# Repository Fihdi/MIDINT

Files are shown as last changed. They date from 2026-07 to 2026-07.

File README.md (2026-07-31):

# 6hp MIDI Interface (work in progress)
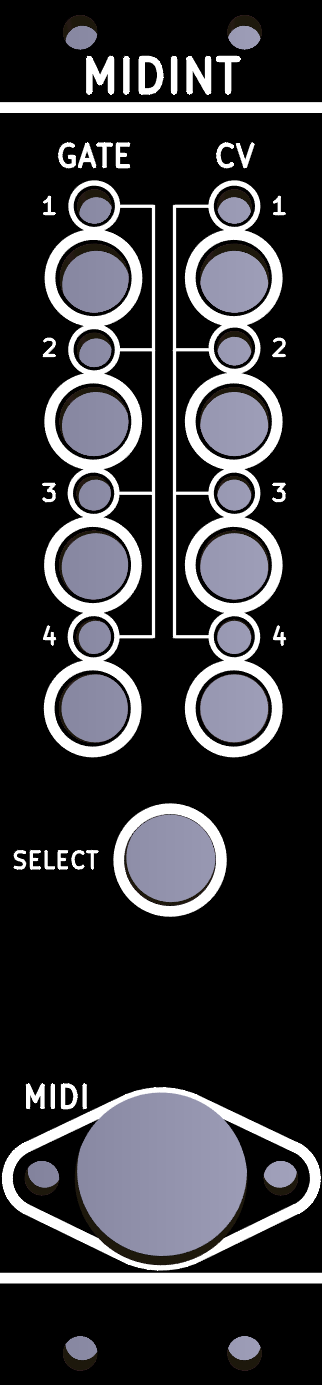
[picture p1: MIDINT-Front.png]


MIDINT is an eight channel MIDI interface in 6hp. Take a standard DIN-5 MIDI cable connected to your favorite DAW or MIDI gear and control up to eight Gate, Trigger and CV channels. Trimmers on the back of the module allow for precise V/Oct tuning. The CV outputs can thus control oscillators and filters without the need for an external quantizer.

Selecting a channel with the "SELECT" encoder and pressing it will switch it between a trigger or gate output.

# Features

- 4 Gate or Trigger outputs
- 4 CV outputs (Can also be used as Gate or Trigger outputs)
- Extension of up to three modules.

# Extension 

Its possible to daisy-chain up to three extension modules to one main module and expand your interface system to a maximum of 32 Gate/Trigger/CV channels. To connect extension module(s) to a main module:

WARNING: Do NOT connect main modules together!

- Turn your modular synthesizer off
- Take an extension module(s) and change the jumper from "MAIN" to "EXT".
- Add jumpers to "EXT1" and "EXT2" to configure the MIDI channels (see table below)
- Connect the extension module(s) to a main module or another extension module in the chain with a wire underneath the power connector.
- Connect each module(s) to power
- Turn your modular synthesizer on

By connecting a MIDI cable into the main module the MIDI data is shared between all modules. The extension modules are addressed by the jumper settings EXT1 and EXT2:

//TODO: Add address table

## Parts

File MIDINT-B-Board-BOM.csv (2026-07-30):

Reference | Qty | Value | DNP | Exclude from BOM | Exclude from Board | Footprint | Datasheet
A101 | 1 | Arduino_Nano_v3.x |  |  |  | Module:Arduino_Nano | http://www.mouser.com/pdfdocs/Gravitech_Arduino_Nano3_0.pdf
C101,C104,C105 | 3 | 100n |  |  |  | Capacitor_SMD:C_1206_3216Metric | ~
C103 | 1 | 10u |  |  |  | Capacitor_SMD:C_1206_3216Metric | ~
D4,D6,D8,D9,D10,D13,D14,D19,D20,D21,D22,D101 | 12 | D |  |  |  | Diode_SMD:D_SOD-323_HandSoldering | ~
J2,J3,J102,J103 | 4 | Conn_01x01_Pin |  |  |  | Connector_PinHeader_2.54mm:PinHeader_1x01_P2.54mm_Vertical | ~
J11 | 1 | Conn_02x05_Odd_Even |  |  |  | Connector_IDC:IDC-Header_2x05_P2.54mm_Vertical | ~
J19,J23 | 2 | Conn_01x04_Pin |  |  |  | Connector_PinHeader_2.54mm:PinHeader_1x04_P2.54mm_Vertical | ~
J104,J106 | 2 | Conn_01x02_Pin |  |  |  | Connector_PinHeader_2.54mm:PinHeader_1x02_P2.54mm_Vertical | ~
J105 | 1 | Conn_02x04_Odd_Even |  |  |  | Connector_PinHeader_2.54mm:PinHeader_2x04_P2.54mm_Vertical | ~
J107 | 1 | Conn_01x03_Pin |  |  |  | Connector_PinHeader_2.54mm:PinHeader_1x03_P2.54mm_Vertical | ~
R1,R2 | 2 | 220R |  |  |  | Resistor_SMD:R_1206_3216Metric | ~
R5,R7,R10,R12,R21,R23,R25,R27,R101,R103,R104 | 11 | 1k |  |  |  | Resistor_SMD:R_1206_3216Metric | ~
R6,R8,R11,R13 | 4 | 22k |  |  |  | Resistor_SMD:R_1206_3216Metric | ~
R19,R22,R24,R26 | 4 | 2k2 |  |  |  | Resistor_SMD:R_1206_3216Metric | ~
R108,R109 | 2 | 4k7 |  |  |  | Resistor_SMD:R_1206_3216Metric | ~
RV1,RV2,RV3,RV4 | 4 | 50k |  |  |  | Potentiometer_THT:Potentiometer_Bourns_3296W_Vertical | ~
U4 | 1 | L7805 |  |  |  | Package_TO_SOT_SMD:SOT-223 | http://www.st.com/content/ccc/resource/technical/document/datasheet/41/4f/b3/b0/12/d4/47/88/CD00000444.pdf/files/CD00000444.pdf/jcr:content/translations/en.CD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
U6 | 1 | TL074 |  |  |  | Package_SO:SOIC-14_3.9x8.7mm_P1.27mm | http://www.ti.com/lit/ds/symlink/tl071.pdf
U101 | 1 | 6N138 |  |  |  | Package_DIP:DIP-8_W7.62mm | http://www.onsemi.com/pub/Collateral/HCPL2731-D.pdf
U102 | 1 | DAC6573 |  |  |  | Package_SO:TSSOP-16_4.4x5mm_P0.65mm

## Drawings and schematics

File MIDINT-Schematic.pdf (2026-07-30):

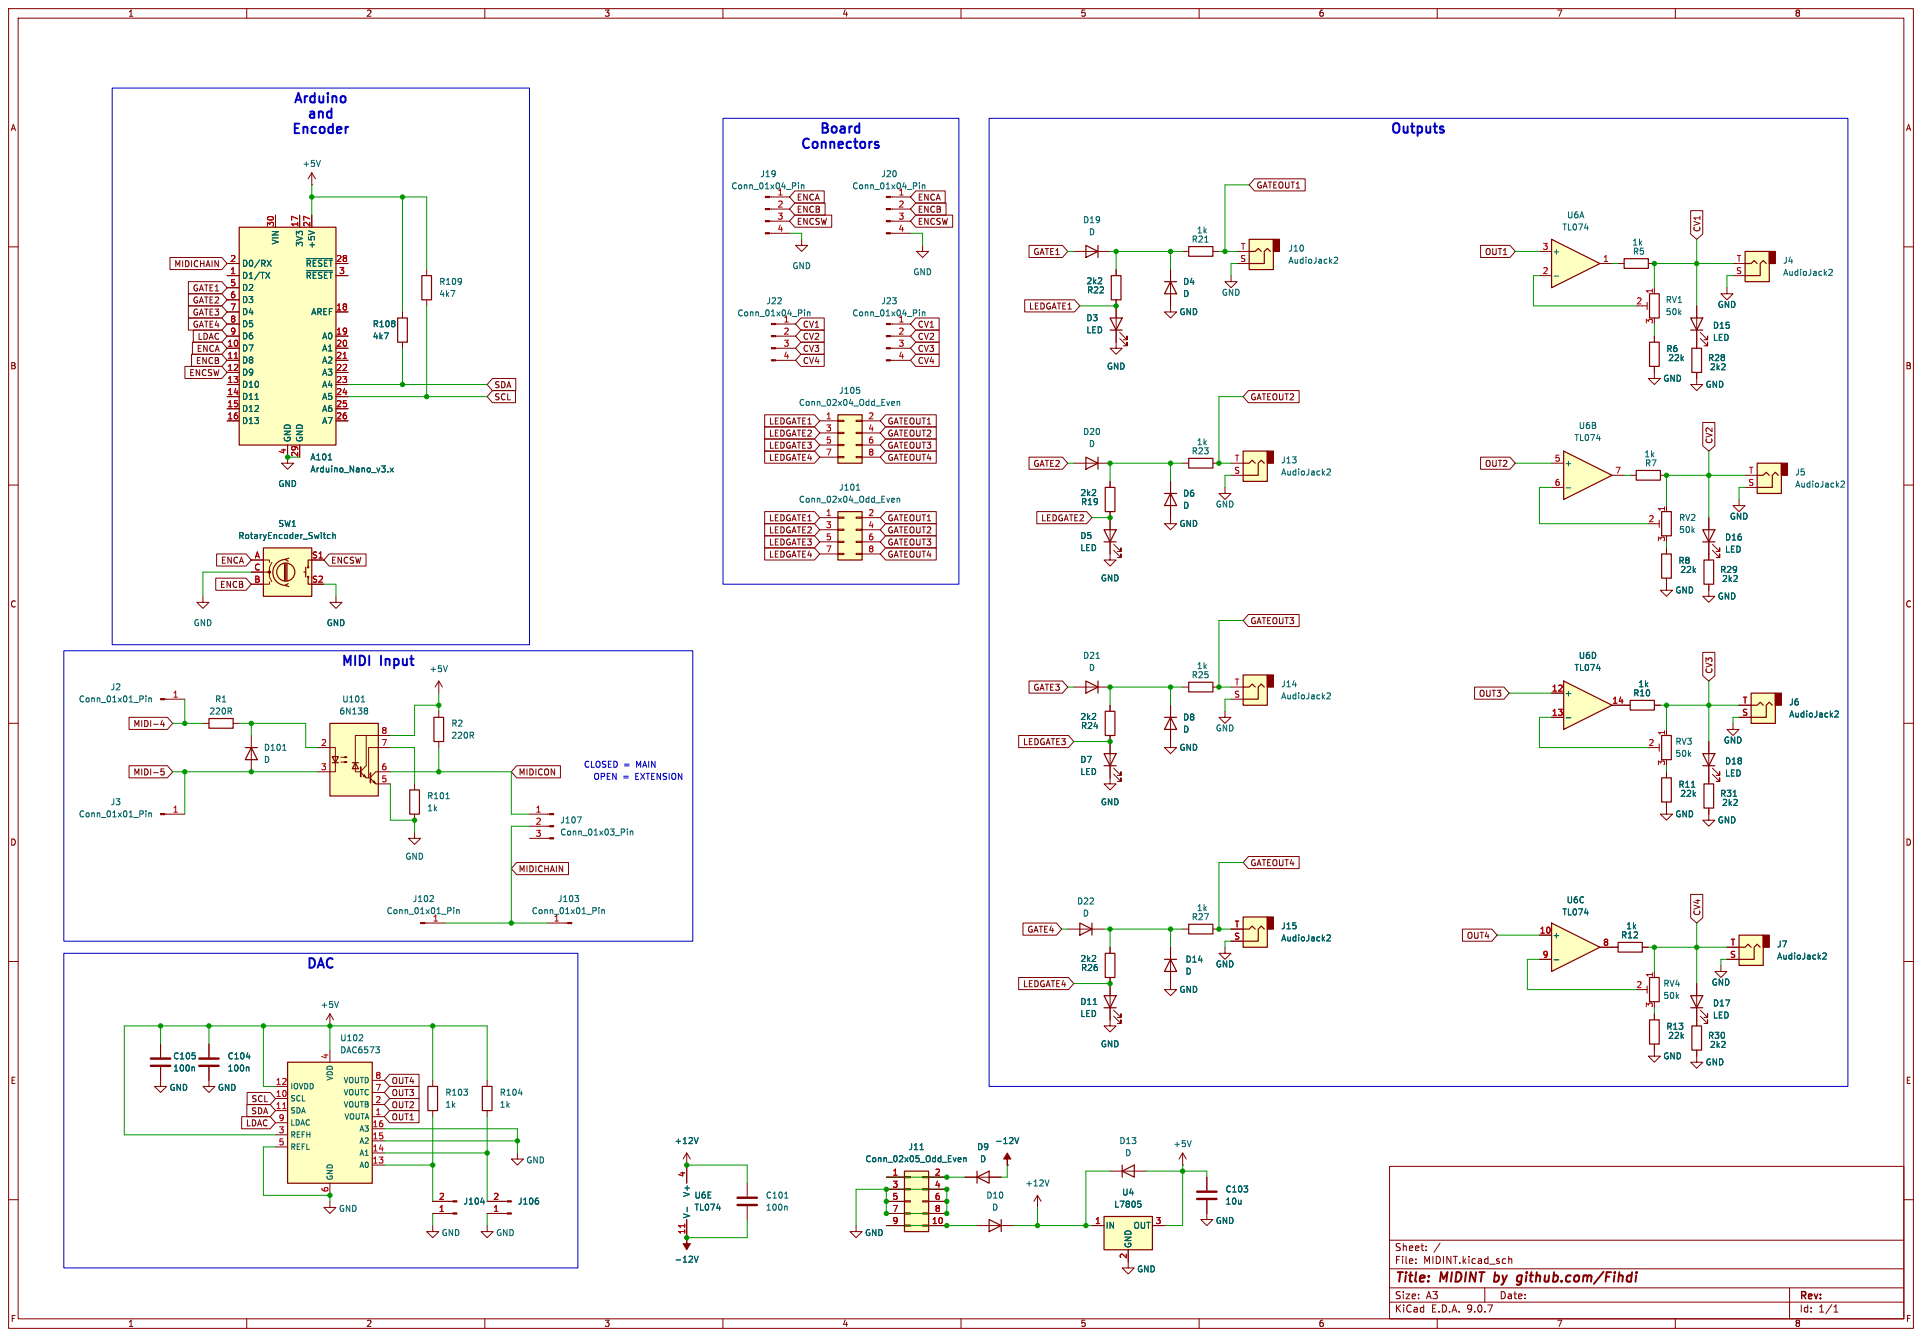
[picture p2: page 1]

CLOSED = MAIN OPEN = EXTENSION

6 VOUTD 8 VOUTC 7 VOUTB 2 VOUTA 1 A3 16 A2 15 A1 14 A0 13 U102 DAC6573 GND

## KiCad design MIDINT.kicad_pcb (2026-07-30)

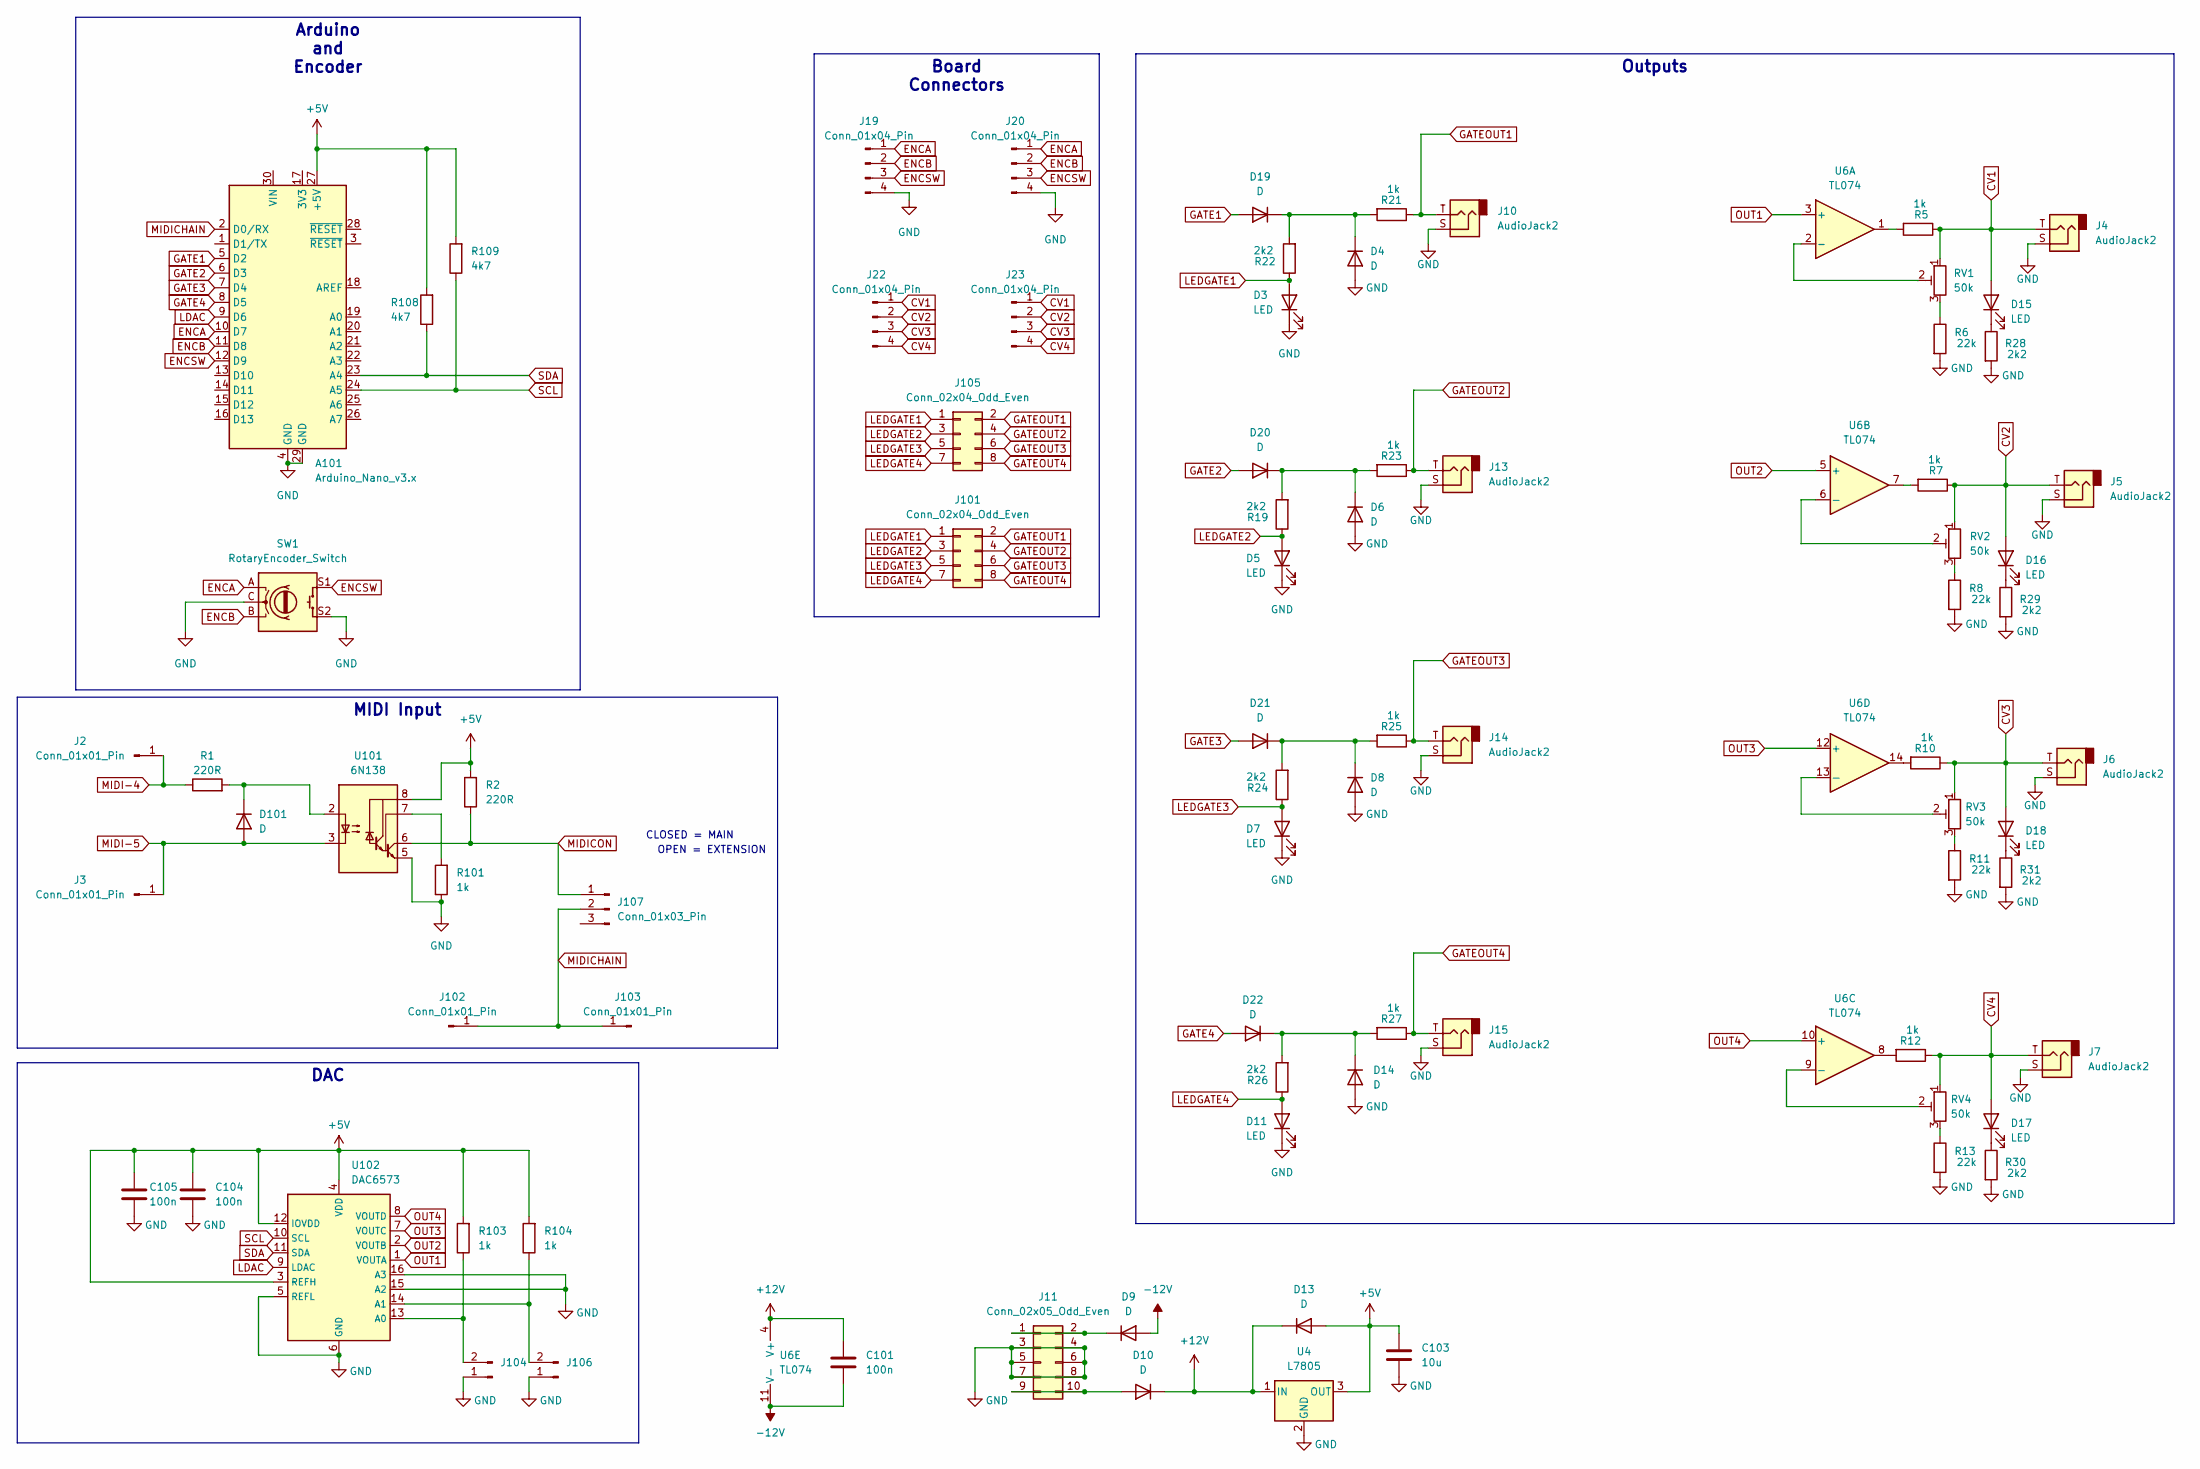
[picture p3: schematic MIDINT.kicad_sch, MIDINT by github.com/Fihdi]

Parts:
A101: Arduino_Nano_v3.x; Arduino_Nano
C101, C104, C105: 100n; C_1206_3216Metric
C103: 10u; C_1206_3216Metric
D3, D5, D7, D11, D15, D16, D17, D18: LED; LED_D3.0mm
D4, D6, D8, D9, D10, D13, D14, D19, D20, D21, D22, D101: D; D_SOD-323_HandSoldering
J2, J3, J102, J103: Conn_01x01_Pin; PinHeader_1x01_P2.54mm_Vertical
J4, J5, J6, J7, J10, J13, J14, J15: AudioJack2; MonoTRS
J11: Conn_02x05_Odd_Even; IDC-Header_2x05_P2.54mm_Vertical
J19, J20, J22, J23: Conn_01x04_Pin; PinHeader_1x04_P2.54mm_Vertical
J101, J105: Conn_02x04_Odd_Even; PinHeader_2x04_P2.54mm_Vertical
J104, J106: Conn_01x02_Pin; PinHeader_1x02_P2.54mm_Vertical
J107: Conn_01x03_Pin; PinHeader_1x03_P2.54mm_Vertical
R1, R2: 220R; R_1206_3216Metric
R5, R7, R10, R12, R21, R23, R25, R27, R101, R103, R104: 1k; R_1206_3216Metric
R6, R8, R11, R13: 22k; R_1206_3216Metric
R19, R22, R24, R26, R28, R29, R30, R31: 2k2; R_1206_3216Metric
R108, R109: 4k7; R_1206_3216Metric
RV1, RV2, RV3, RV4: 50k; Potentiometer_Bourns_3296W_Vertical
SW1: RotaryEncoder_Switch; RotaryEncoder_Alps_EC12E-Switch_Vertical_H20mm
U4: L7805; SOT-223
U6: TL074; SOIC-14_3.9x8.7mm_P1.27mm
U101: 6N138; DIP-8_W7.62mm
U102: DAC6573; TSSOP-16_4.4x5mm_P0.65mm

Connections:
+5V: A101.27 (+5V), C103.1, C104.1, C105.1, D13.2 (A), R2.2, R103.2, R104.2, R108.2, R109.2, U4.3 (OUT), U101.8 (VCC), U102.3 (REFH), U102.4 (VDD), U102.12 (IOVDD)
+12V: C101.1, D10.1 (K), D13.1 (K), U4.1 (IN), U6.4 (V+)
-12V: C101.2, D9.2 (A), U6.11 (V-)
CV1: D15.2 (A), J4.T, J22.1, J23.1, R5.1, RV1.1
CV2: D16.2 (A), J5.T, J22.2, J23.2, R7.1, RV2.1
CV3: D18.2 (A), J6.T, J22.3, J23.3, R10.1, RV3.1
CV4: D17.2 (A), J7.T, J22.4, J23.4, R12.1, RV4.1
ENCA: A101.10 (D7), J19.1, J20.1, SW1.A
ENCB: A101.11 (D8), J19.2, J20.2, SW1.B
ENCSW: A101.12 (D9), J19.3, J20.3, SW1.S1
GATE1: A101.5 (D2), D19.2 (A)
GATE2: A101.6 (D3), D20.2 (A)
GATE3: A101.7 (D4), D21.2 (A)
GATE4: A101.8 (D5), D22.2 (A)
GATEOUT1: J10.T, J101.2, J105.2, R21.1
GATEOUT2: J13.T, J101.4, J105.4, R23.1
GATEOUT3: J14.T, J101.6, J105.6, R25.1
GATEOUT4: J15.T, J101.8, J105.8, R27.1
GND: A101.4 (GND), A101.29 (GND), C103.2, C104.2, C105.2, D3.1 (K), D4.2 (A), D5.1 (K), D6.2 (A), D7.1 (K), D8.2 (A), D11.1 (K), D14.2 (A), J4.S, J5.S, J6.S, J7.S, J10.S, J11.3, J11.4, J11.5, J11.6, J11.7, J11.8, J13.S, J14.S, J15.S, J19.4, J20.4, J104.1, J106.1, R6.2, R8.2, R11.2, R13.2, R28.2, R29.2, R30.2, R31.2, R101.1, SW1.C, SW1.S2, U4.2 (GND), U101.5 (GND), U102.5 (REFL), U102.6 (GND), U102.15 (A2), U102.16 (A3)
LDAC: A101.9 (D6), U102.9 (LDAC)
LEDGATE1: D3.2 (A), J101.1, J105.1, R22.1
LEDGATE2: D5.2 (A), J101.3, J105.3, R19.1
LEDGATE3: D7.2 (A), J101.5, J105.5, R24.1
LEDGATE4: D11.2 (A), J101.7, J105.7, R26.1
MIDI-4: J2.1, R1.1
MIDI-5: D101.2 (A), J3.1, U101.3 (C2)
MIDICHAIN: A101.2 (D0/RX), J102.1, J103.1, J107.2
MIDICON: J107.1, R2.1, U101.6 (VO2)
unnamed: D9.1 (K), J11.1, J11.2
unnamed: D10.2 (A), J11.9, J11.10
unnamed: D14.1 (K), D22.1 (K), R26.2, R27.2
unnamed: D15.1 (K), R28.1
unnamed: D16.1 (K), R29.1
unnamed: D17.1 (K), R30.1
unnamed: D18.1 (K), R31.1
unnamed: D4.1 (K), D19.1 (K), R21.2, R22.2
unnamed: D6.1 (K), D20.1 (K), R19.2, R23.2
unnamed: D8.1 (K), D21.1 (K), R24.2, R25.2
unnamed: D101.1 (K), R1.2, U101.2 (C1)
unnamed: J104.2, R103.1, U102.13 (A0)
unnamed: J106.2, R104.1, U102.14 (A1)
unnamed: R5.2, U6.1
unnamed: R6.1, RV1.3
unnamed: R7.2, U6.7
unnamed: R8.1, RV2.3
unnamed: R10.2, U6.14
unnamed: R11.1, RV3.3
unnamed: R12.2, U6.8
unnamed: R13.1, RV4.3
unnamed: RV1.2, U6.2 (-)
unnamed: RV2.2, U6.6 (-)
unnamed: RV4.2, U6.9 (-)
unnamed: RV3.2, U6.13 (-)
unnamed: R101.2, U101.7 (VO1)
OUT1: U6.3 (+), U102.1 (VOUTA)
OUT2: U6.5 (+), U102.2 (VOUTB)
OUT3: U6.12 (+), U102.7 (VOUTC)
OUT4: U6.10 (+), U102.8 (VOUTD)
SCL: A101.24 (A5), R109.1, U102.10 (SCL)
SDA: A101.23 (A4), R108.1, U102.11 (SDA)

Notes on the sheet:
CLOSED = MAIN
OPEN = EXTENSION
MIDI Input
DAC
Board Connectors
Arduino and Encoder
Outputs

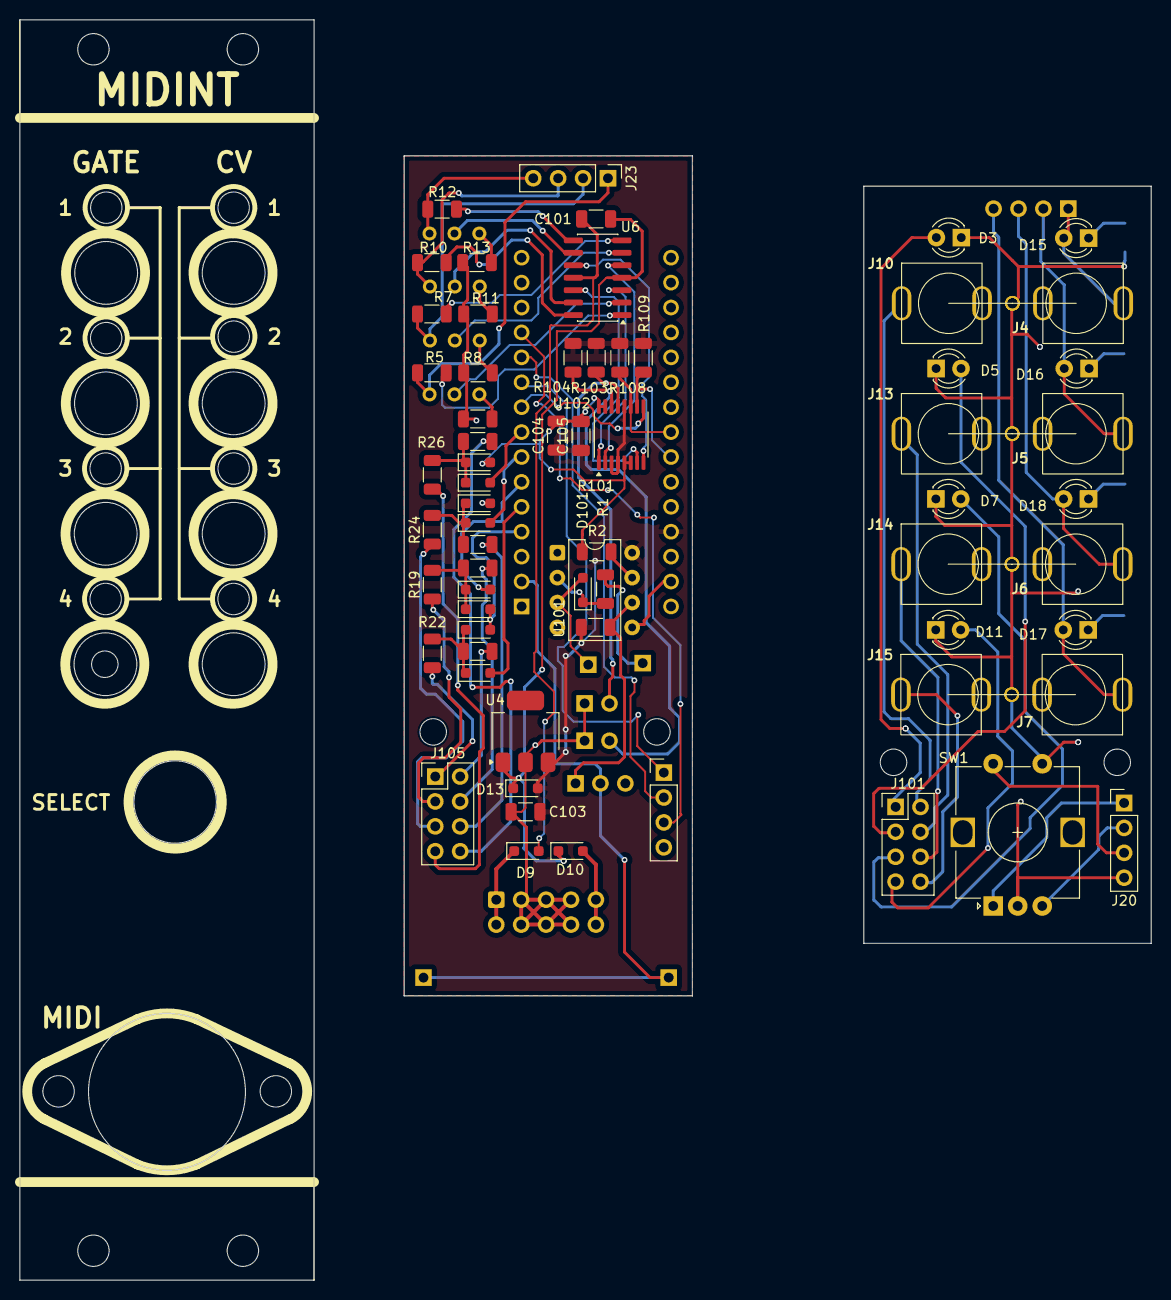
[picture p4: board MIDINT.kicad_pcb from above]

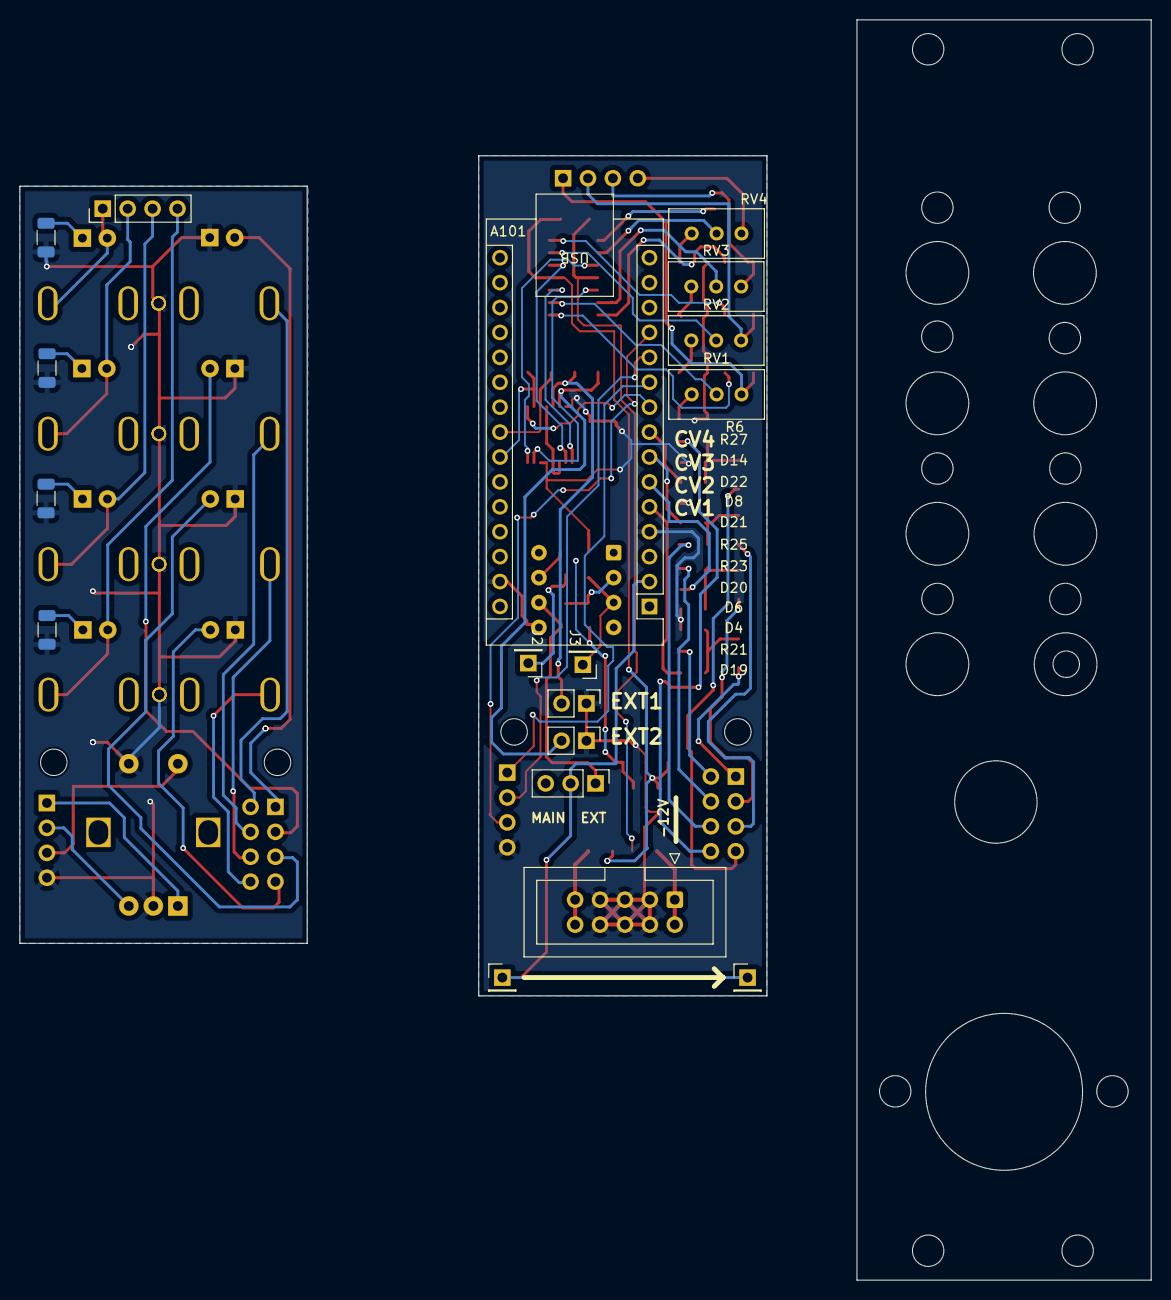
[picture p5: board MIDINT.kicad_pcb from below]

Board: 2 copper layers, 115.4 x 128.5 mm, 83 parts (18 on the bottom side), 60 nets.
